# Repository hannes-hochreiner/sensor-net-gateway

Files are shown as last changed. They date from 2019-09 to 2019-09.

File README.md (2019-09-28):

# Sensor Net Gateway
A gateway for translating messages from the sensor net sensors to USB CDC.

## Pre-Order PCB Checklist
  * [x] ground flood
  * [x] surround antenna traces with vias
  * [x] change LDO footprint
  * [x] change connector footprint
  * [x] interrupt lines
  * [x] diagram cleanup
  * [x] diagram check
  * [x] layout check

# Post Assembly Checks

## Electrical Check
On visual inspection, the connections looked pretty good.
To make sure nothing major went wrong, I checked for shorts, especially between power and ground.
I also checked that ground was connected to the right side of the electrolytic capacitor.

## FTDI
My first check of the FTDI chip was to simply connect the board and check the output of dmsg:
```
[862594.355360] Indeed it is in host mode hprt0 = 00021501
[862594.565069] usb 1-1: new full-speed USB device number 2 using dwc_otg
[862594.565389] Indeed it is in host mode hprt0 = 00021501
[862594.812139] usb 1-1: New USB device found, idVendor=0403, idProduct=6015, bcdDevice=10.00
[862594.812159] usb 1-1: New USB device strings: Mfr=1, Product=2, SerialNumber=3
[862594.812168] usb 1-1: Product: FT230X Basic UART
[862594.812176] usb 1-1: Manufacturer: FTDI
[862594.812184] usb 1-1: SerialNumber: DM01KPIW
[862594.947315] usbcore: registered new interface driver usbserial_generic
[862594.947420] usbserial: USB Serial support registered for generic
[862594.963184] usbcore: registered new interface driver ftdi_sio
[862594.963293] usbserial: USB Serial support registered for FTDI USB Serial Device
[862594.963573] ftdi_sio 1-1:1.0: FTDI USB Serial Device converter detected
[862594.963800] usb 1-1: Detected FT-X
[862594.997482] usb 1-1: FTDI USB Serial Device converter now attached to ttyUSB0
```
## Power
Next, I checked the power rail after the two-stage conversion.
I got 2.75 V, which is a bit lower than expected, but within specification (2.8 V +/- 3%) and still ok for my use.

## UART communication
UART communication without hardware flow control worked fine, after I switched TX and RX (see [issue TX-RX and CTS-RTS inverted](#TX-RX-and-CTS-RTS-inverted) below).
I have tried running the interface at 10 kHz, 100 kHz, and 1 MHz.
So far, I was only successful at 10 kHz.
My suspicion is that the internal high-speed clock of the STM32 is not precise enough.

## RFM98
The RFM98 works as expected.
The RSSI is around -95 dBm, which is lower than I hoped.
With the breakout board and a different antenna, I have seen a typical RSSI around -65 dBm.
So there is some potential for improvement here by using different antennas.
Since the module claims to have a sensitivity down to -148 dBm, I think I should be fine.
From what I have seen, most of the sensor transmissions were picked up.

## Authentication chip
So far, I have not been able to convince the authentication chip to respond.
I have tried different addresses and also implemented the wake-up sequence.
My suspicion is that I did not properly solder it.

## External oscillator
I could not get a stable signal from the external oscillator.
Probably also a case for re-soldering.

# Issues
## TX-RX and CTS-RTS inverted
When I wired up the schematic, I made the mistake to connect TX to TX, RX to RX, and so on.
While this works fine for SPI and I2C, it does not work for UART.
With UART, TX has to be connected to RX and CTS to RTS.
The saving grace is that the STM32 has an option to swap TX and RX lines.
Seems that I am not the first one to make this mistake :-).

CTS and RTS cannot be swapped in the chip, so in this iteration I won't be able to use the integrated hardware flow control.
Since I am using the UART interface based on interrupts, it should be easily possible to set the RTS and CTS lines manually.

## Cut-outs seem off
The PCB fits fine into the case, but the margins are not uniform.
Therefore, I want to go back and check the cut-outs.

# Hardware to order
## Screws
Self-tapping screws [Amazon link](https://www.amazon.de/Baoyl-Office-Cutting-Tapping-Printer-Accessories/dp/B07VX7XYYC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)

## Hub
USB-hub [Amazon link](https://www.amazon.de/CSL-aktiver-schaltbar-Verteiler-Notebook/dp/B07F2Q94CT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)

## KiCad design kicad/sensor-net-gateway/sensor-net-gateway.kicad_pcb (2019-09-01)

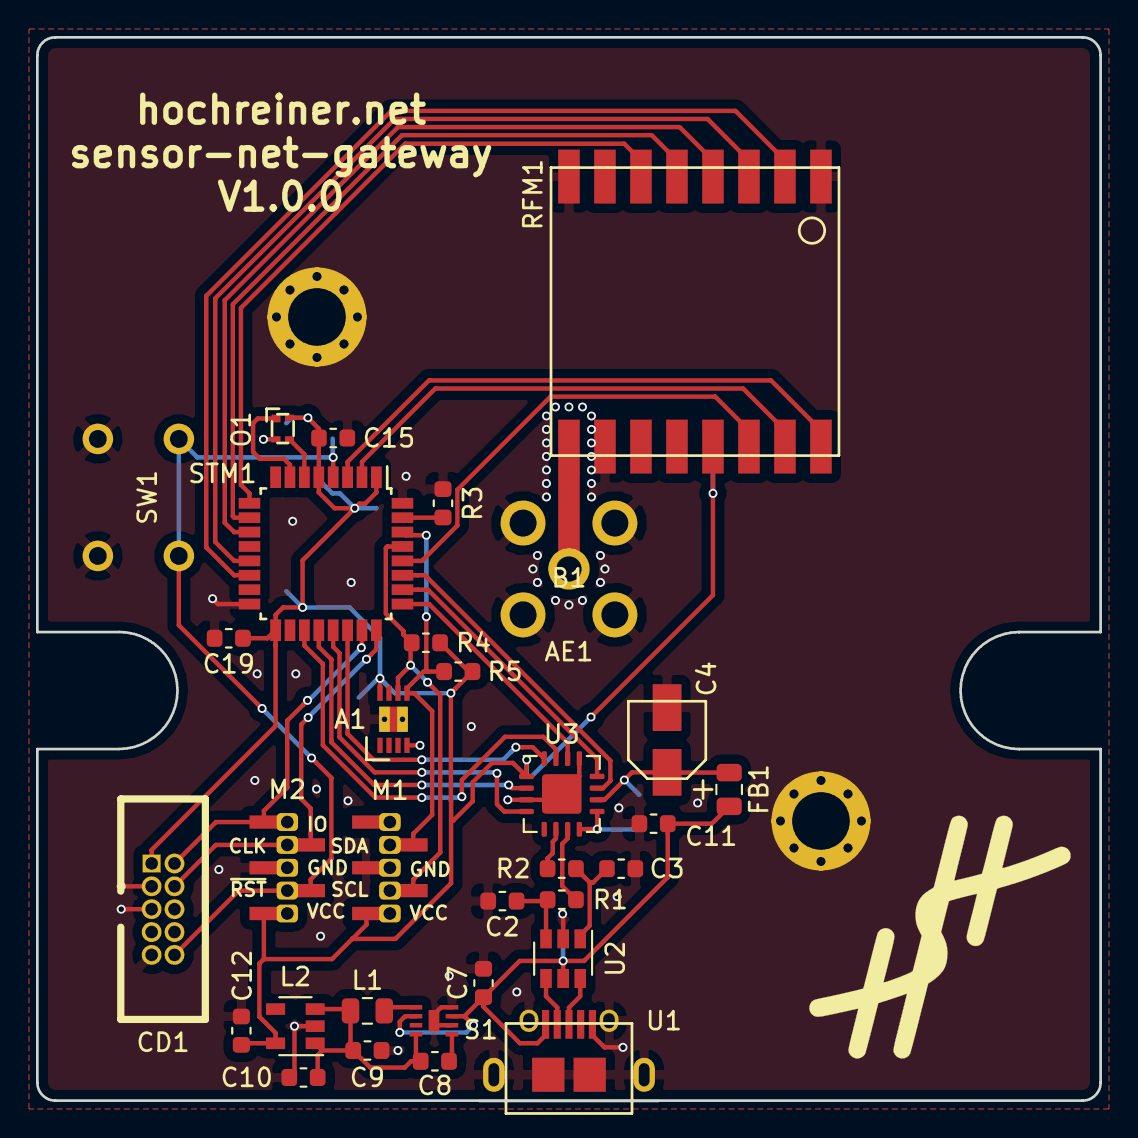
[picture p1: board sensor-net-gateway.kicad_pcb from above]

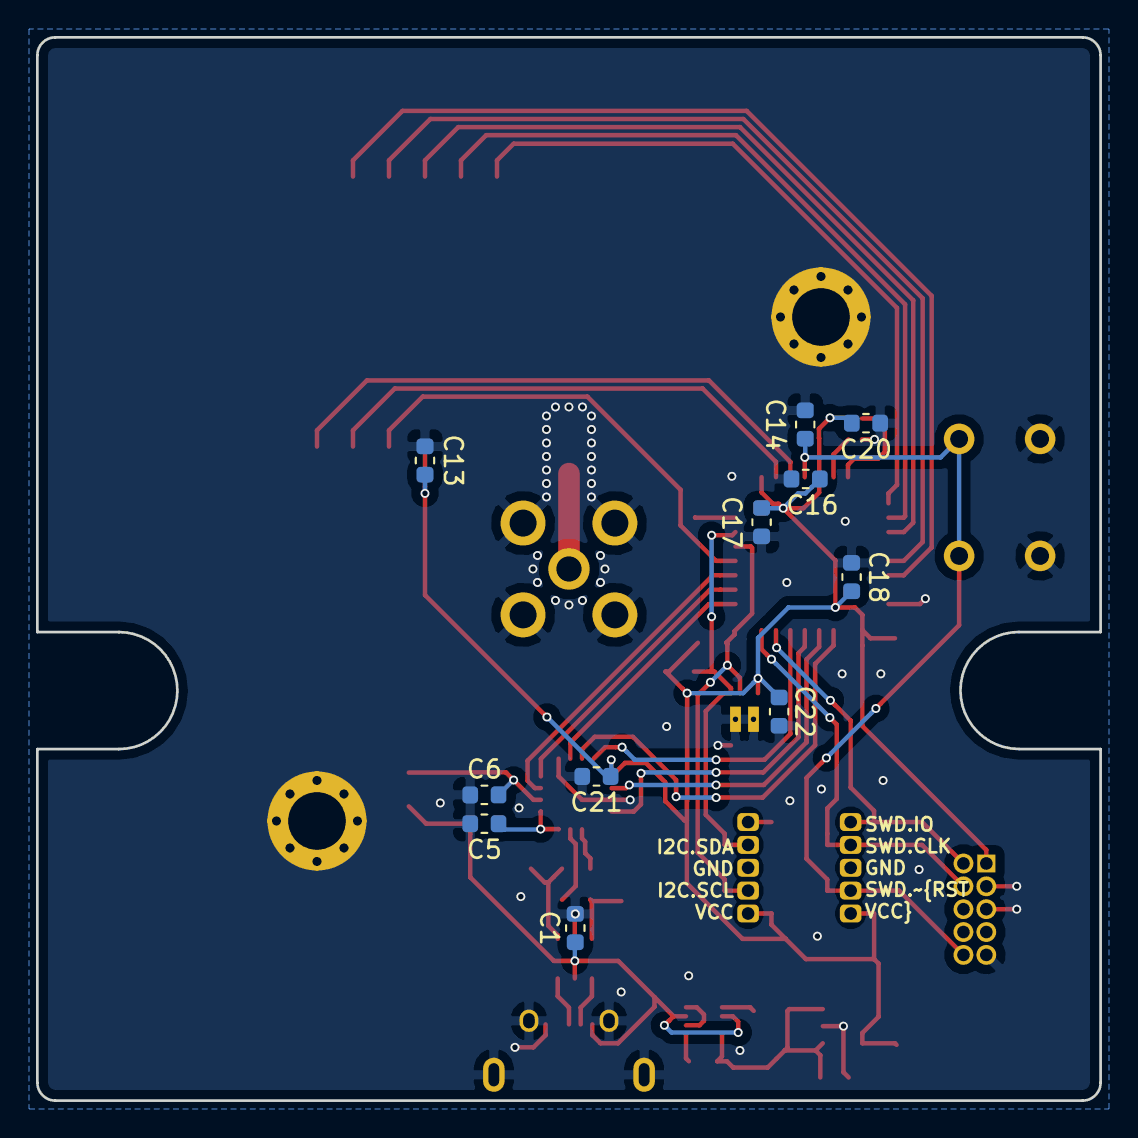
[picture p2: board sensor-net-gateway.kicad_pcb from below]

Board: 2 copper layers, 59.1 x 59.1 mm, 45 parts (11 on the bottom side), 38 nets.

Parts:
A1: ATECC508A-MAHCZ-S
AE1: Antenna_Shield; CONSMA001-G
B1: 1593JGY
C1, C5, C6, C13, C14, C16, C17, C18, C20, C21, C22: 0.1µF; C_0603_1608Metric
C2, C3: 47pF; C_0603_1608Metric
C4: 4.7µF; 865080640004
C7, C9: 4.7µF; C_0603_1608Metric
C8: 560pF; C_0603_1608Metric
C10: 0.47µF; C_0603_1608Metric
C11: 10nF; C_0603_1608Metric
C12, C19: 10µF; C_0603_1608Metric
C15: 1µF; C_0603_1608Metric
CD1: CORTEX-DEBUG
FB1: Ferrite_Bead; C_0805_2012Metric
L1: 1µH; L_0805_2012Metric
L2: MIC94310-MYM5-TR; SOT-23-5
L3: logo
M1, M2: M50-3130545
O1: DSC6011HE2A-032.0000
R1, R2: 27R; R_0603_1608Metric
R3, R4, R5: 10k; R_0603_1608Metric
RFM1: RFM98
S1: MIC23050-SYML-TR
STM1: STM32L021K4T6; LQFP-32_7x7mm_P0.8mm
SW1: SW_Push; 1825910-6
U1: USB_micro_ab; MOLEX_USB_MICRO_0475890001
U2: USBLC6-2SC6; SOT-23-6
U3: FT230XQ; QFN-16-1EP_4x4mm_P0.65mm_EP2.7x2.7mm

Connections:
/3V0: A1.8, C12.1, C13.1, C15.1, C16.1, C17.2, C18.1, C19.1, C20.1, C21.1, C22.1, CD1.1, L2.5, M1.1, M2.1, O1.4, R4.2, R5.2, RFM1.13, STM1.1, STM1.5, STM1.17, U3.1
/FTDI_IO0: STM1.26, U3.12
/FTDI_IO1: STM1.27, U3.11
/FTDI_IO3: STM1.25, U3.14
/MCU/I2C.SCL: A1.6, M1.2, R4.1, STM1.29
/MCU/I2C.SDA: A1.5, M1.4, R5.1, STM1.30
/MCU/OSC: O1.3, STM1.6
/MCU/OSC_EN: O1.1, STM1.7
/MCU/SWD_CLK: CD1.4, M2.4, STM1.24
/MCU/SWD_IO: CD1.2, M2.5, STM1.23
/MCU/~SWD_RST: C14.1, CD1.10, M2.2, STM1.4, SW1.2
/RFM_DIO0: RFM1.14, STM1.28
/RFM_DIO1: RFM1.15, STM1.2
/RFM_DIO2: RFM1.16, STM1.3
/RFM_RESET: RFM1.6, STM1.9
/Radio/ANT: AE1.1, RFM1.9
/SPI.MISO: RFM1.2, STM1.14
/SPI.MOSI: RFM1.3, STM1.13
/SPI.SCK: RFM1.4, STM1.11
/SPI.~CS: RFM1.5, STM1.10
/UART.CTS: STM1.21, U3.4
/UART.RTS: STM1.22, U3.16
/UART.RX: STM1.20, U3.2
/UART.TX: STM1.19, U3.15
/VBUS: C1.1, C7.1, C11.1, FB1.2, S1.2, S1.7, U1.1, U2.5
GND: A1.4, AE1.2, B1.1, C1.2, C2.2, C3.2, C4.2, C5.2, C6.1, C7.2, C9.2, C10.2, C11.2, C12.2, C13.2, C14.2, C15.2, C16.2, C17.1, C18.2, C19.2, C20.2, C21.2, C22.2, CD1.3, CD1.5, CD1.9, L2.2, M1.3, M2.3, O1.2, R3.2, RFM1.1, RFM1.8, RFM1.10, S1.6, S1.8, STM1.16, STM1.32, SW1.1, U1.5, U2.2, U3.3, U3.13, U3.17
unnamed: C2.1, R1.2, U2.3
unnamed: C3.1, R2.2, U2.1
unnamed: C4.1, C6.2, FB1.1, U3.10
unnamed: C5.1, U3.8, U3.9
unnamed: C8.2, S1.5
unnamed: C8.1, C9.1, C10.1, L1.2, L2.1, L2.3, S1.4
unnamed: L1.1, S1.1
unnamed: R1.1, U3.7
unnamed: R2.1, U3.6
unnamed: R3.1, STM1.31
unnamed: U1.2, U2.4
unnamed: U1.3, U2.6

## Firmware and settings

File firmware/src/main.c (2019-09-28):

#include "main.h"

void infiniteLoop() {
  while (1) {
    __NOP();
  }
}

#define CHECK_RESULT(fun) if(fun != RESULT_OK) { infiniteLoop(); }

int main() {
  volatile result_t res;

  // switch_to_external();

  CHECK_RESULT(switch_to_hsi16());
  SystemCoreClockUpdate();

  CHECK_RESULT(rtc_init());
  spi_init();
  // res = i2c_init();
  pin_reset_init();
  CHECK_RESULT(rfm9x_g_init());

  if ((GPIOB->IDR & GPIO_IDR_ID5) == GPIO_IDR_ID5) {
    rfm9x_g_get_message(&rfm_read_message);
  }

  CHECK_RESULT(uart_init());
  CHECK_RESULT(rfm9x_g_start_reception());

  const uint8_t bTx[] = "{\"type\":\"info\",\"message\":\"sensor net gateway starting\"}\n";
  // uint8_t bRx[10];
  uart_tx_t uTx = {
    .buffer = bTx,
    .length = sizeof(bTx)
  };
  uart_write(&uTx);
  // uart_rx_t uRx = {
  //   .buffer = bRx,
  //   .length = 10,
  //   .callback = &uart_rx_cb
  // };

  rtc_wait_until_next_period();

  while (1) {
    if (rfm9x_g_get_message_pending()) {
      rfm9x_g_get_message(&rfm_read_message);
    }

    // if ((GPIOB->IDR & GPIO_IDR_ID5) == GPIO_IDR_ID5) {
    //   rfm9x_g_get_message(&rfm_read_message);
    // }
    // result_t res_meas = bme280_g_measurement(&meas_data_new);
    // volatile boolean_t skip = BOOL_TRUE;

    // GPIOB->MODER = (GPIOB->MODER & ~(GPIO_MODER_MODE7)) | (GPIO_MODER_MODE7_0);
    // GPIOB->BSRR |= GPIO_BSRR_BR_7;
    // for (uint32_t cntr = 0; cntr < 2000; cntr++) {
    //   __NOP();
    // }
    // GPIOB->BSRR |= GPIO_BSRR_BS_7;
    // GPIOB->MODER = (GPIOB->MODER & ~(GPIO_MODER_MODE7)) | (GPIO_MODER_MODE7_1);

    // uint8_t data[] = {0x00};
    // // 0xC0
    // res = i2c_write(0x60, data, 1);

    // uint8_t enc_data[32];
    // aes_key_t key = {KEY0, KEY1, KEY2, KEY3};
    // aes_ecb_encrypt(&key, (uint32_t*)&msg, (uint32_t*)enc_data, 8);
    // rfm9x_g_send_message(enc_data, 32);

    // uart_write(&uTx);
    // uart_read(&uRx);

    // while (USART2->ISR & USART_ISR_RXNE) {
    //   volatile uint8_t tmp = USART2->RDR;
    //   volatile uint8_t tmp2 = 5;
    // }
    // stop_enable();
    // rtc_wait_until_next_period();
    // stop_disable();
    __WFI();
  }
}

void uart_rx_cb(uint32_t length) {
  volatile uint32_t tmp = length;
}

void rfm_read_message(const uint8_t* const data, uint16_t length) {
  if (length > 256) {
    return;
  }

  int rssi;
  rfm9x_g_get_rssi(&rssi);
  const char* startFormat = "{\"type\":\"rfm\",\"rssi\":\"%i\",\"data\":\"";
  const char* endFormat = "\"}\n";
  const char* hexFormat = "%02X";
  int lengthStart = snprintf(NULL, 0, startFormat, rssi);
  int lengthData = length * 2;
  int lengthEnd = strlen(endFormat);
  int lengthTotal = lengthStart + lengthData + lengthEnd;

  char message[lengthTotal + 1];
  int idx = sprintf(message, startFormat, rssi);

  for (uint16_t cntr = 0; cntr < length; cntr++) {
    sprintf(message + idx, hexFormat, data[cntr]);
    idx += 2;
  }

  sprintf(message + idx, endFormat);

  uart_tx_t uTx = {
    .buffer = message,
    .length = lengthTotal
  };
  volatile result_t res = uart_write(&uTx);
}

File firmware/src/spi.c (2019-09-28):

#include "spi.h"

static volatile status_t status_dma_tx = STATUS_PENDING;
static volatile status_t status_dma_rx = STATUS_PENDING;

void spi_dma_c2_3_handler();

void spi_init() {
  RCC->AHBENR |= (RCC_AHBENR_DMAEN);
  RCC->APB2ENR |= (RCC_APB2ENR_SPI1EN);
  RCC->IOPENR |= (RCC_IOPENR_IOPAEN);
  RCC->IOPENR |= (RCC_IOPENR_IOPBEN);

  // PA7 (MOSI), PB0 (MISO), and PA5 (SCK) are initialized to "alternate function push/pull", without pull ups/downs, at very high speed.
  // PA4 (NCS) is initialized to push/pull
  GPIOA->MODER = (GPIOA->MODER & ~(GPIO_MODER_MODE4)) | (GPIO_MODER_MODE4_0);
  GPIOA->MODER = (GPIOA->MODER & ~(GPIO_MODER_MODE5)) | (GPIO_MODER_MODE5_1);
  GPIOB->MODER = (GPIOB->MODER & ~(GPIO_MODER_MODE0)) | (GPIO_MODER_MODE0_1);
  GPIOA->MODER = (GPIOA->MODER & ~(GPIO_MODER_MODE7)) | (GPIO_MODER_MODE7_1);
  GPIOA->OSPEEDR = (GPIOA->OSPEEDR & ~(GPIO_OSPEEDER_OSPEED4)) | (GPIO_OSPEEDER_OSPEED4_0) | (GPIO_OSPEEDER_OSPEED4_1);
  GPIOA->OSPEEDR = (GPIOA->OSPEEDR & ~(GPIO_OSPEEDER_OSPEED5)) | (GPIO_OSPEEDER_OSPEED5_0) | (GPIO_OSPEEDER_OSPEED5_1);
  GPIOB->OSPEEDR = (GPIOB->OSPEEDR & ~(GPIO_OSPEEDER_OSPEED0)) | (GPIO_OSPEEDER_OSPEED0_0) | (GPIO_OSPEEDER_OSPEED0_1);
  GPIOA->OSPEEDR = (GPIOA->OSPEEDR & ~(GPIO_OSPEEDER_OSPEED7)) | (GPIO_OSPEEDER_OSPEED7_0) | (GPIO_OSPEEDER_OSPEED7_1);

  GPIOB->AFR[0] = (GPIOB->AFR[0] & ~(GPIO_AFRL_AFSEL0)) | (0b0001 << GPIO_AFRL_AFSEL0_Pos);

  GPIOA->BSRR = (GPIO_BSRR_BS_4);
 
  SPI1->CR1 = ((SPI_CR1_MSTR) | (SPI_CR1_SSM) | (SPI_CR1_SSI));
  // set baud rate to f_clk / 2 (with HSI at 16 MHz => 8 MHz)
  SPI1->CR1 &= ~SPI_CR1_BR;
  SPI1->CR2 = ((SPI_CR2_TXDMAEN) | (SPI_CR2_RXDMAEN));
}

void spi_transfer(uint8_t* const data, uint16_t length) {
  // RX channel 2
  // TX channel 3
  // set CMAR (MA), CPAR (PA), CNDTR (NDT), CCR (EN)
  DMA1_Channel2->CCR = (DMA_CCR_MINC) | (DMA_CCR_TEIE) | (DMA_CCR_TCIE);
  DMA1_Channel3->CCR = (DMA_CCR_MINC) | (DMA_CCR_TEIE) | (DMA_CCR_TCIE) | (DMA_CCR_DIR);
  DMA1_CSELR->CSELR = (1 << (DMA_CSELR_C2S_Pos)) | (1 << (DMA_CSELR_C3S_Pos));

  DMA1_Channel2->CNDTR = length;
  DMA1_Channel3->CNDTR = length;
  DMA1_Channel2->CPAR = (uint32_t)(&(SPI1->DR));
  DMA1_Channel3->CPAR = (uint32_t)(&(SPI1->DR));
  DMA1_Channel2->CMAR = (uint32_t)data;
  DMA1_Channel3->CMAR = (uint32_t)data;
  DMA1_Channel2->CCR |= (DMA_CCR_EN);
  DMA1_Channel3->CCR |= (DMA_CCR_EN);

  status_dma_tx = STATUS_PENDING;
  status_dma_rx = STATUS_PENDING;

  add_handler(DMA1_Channel2_3_IRQn, spi_dma_c2_3_handler);
  NVIC_EnableIRQ(DMA1_Channel2_3_IRQn);
  
  SPI1->CR1 |= (SPI_CR1_SPE);
  GPIOA->BSRR = GPIO_BSRR_BR_4;

  while ((status_dma_rx == STATUS_PENDING) || (status_dma_tx == STATUS_PENDING)) {
    __WFI();
  }

  GPIOA->BSRR = GPIO_BSRR_BS_4;
  SPI1->CR1 &= ~(SPI_CR1_SPE);

  DMA1_Channel2->CCR = 0;
  DMA1_Channel3->CCR = 0;
  NVIC_DisableIRQ(DMA1_Channel2_3_IRQn);
  remove_handler(DMA1_Channel2_3_IRQn, spi_dma_c2_3_handler);
}

void spi_dma_c2_3_handler() {
  uint32_t status = (DMA1->ISR);
  
  DMA1->IFCR |= DMA_IFCR_CGIF2;
  DMA1->IFCR |= DMA_IFCR_CGIF3;

  if ((status & (DMA_ISR_TEIF2)) == (DMA_ISR_TEIF2)) {
    status_dma_rx = STATUS_ERROR;
  } else if ((status & (DMA_ISR_TCIF2)) == (DMA_ISR_TCIF2)) {
    status_dma_rx = STATUS_OK;
  }
  
  if ((status & (DMA_ISR_TEIF3)) == (DMA_ISR_TEIF3)) {
    status_dma_tx = STATUS_ERROR;
  } else if ((status & (DMA_ISR_TCIF3)) == (DMA_ISR_TCIF3)) {
    status_dma_tx = STATUS_OK;
  }
}

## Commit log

2019-09-01 finished initial layout
    [mcu.sch, radio.sch, sensor-net-gateway.kicad_pcb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]
2019-09-16 added first post assembly checks
2019-09-28 added test firmware
    [oo.cfg, oo_prod.cfg]
2019-09-28 set SPI to 8 MHz
